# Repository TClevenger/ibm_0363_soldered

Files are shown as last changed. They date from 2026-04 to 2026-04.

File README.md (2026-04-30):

# IBM_0363_soldered

An alternative to the unobtainium/exhorbitantly expensive IBM 0363 (45H2433) port box for the Integrated Netfinity PC on the AS/400 Model 150 and probably others.  This breaks out the PS/2 keyboard and mouse ports from the MDR-40 mini-delta connector on the back of the Netfinity card set.  

This board is tested to fit CUI MD-60S Mini-DIN ports and uses any four-pair cable to connect to a 3M 10140-3000PE "solder cup" style connector.  Gerbers were made using JLCPCB template.

Current release is V1R1 (2026-04-30)
* Expanded pad size, added header vias, cleaned up silkscreen markings, narrowed strain relief holes
* Added LICENSE file

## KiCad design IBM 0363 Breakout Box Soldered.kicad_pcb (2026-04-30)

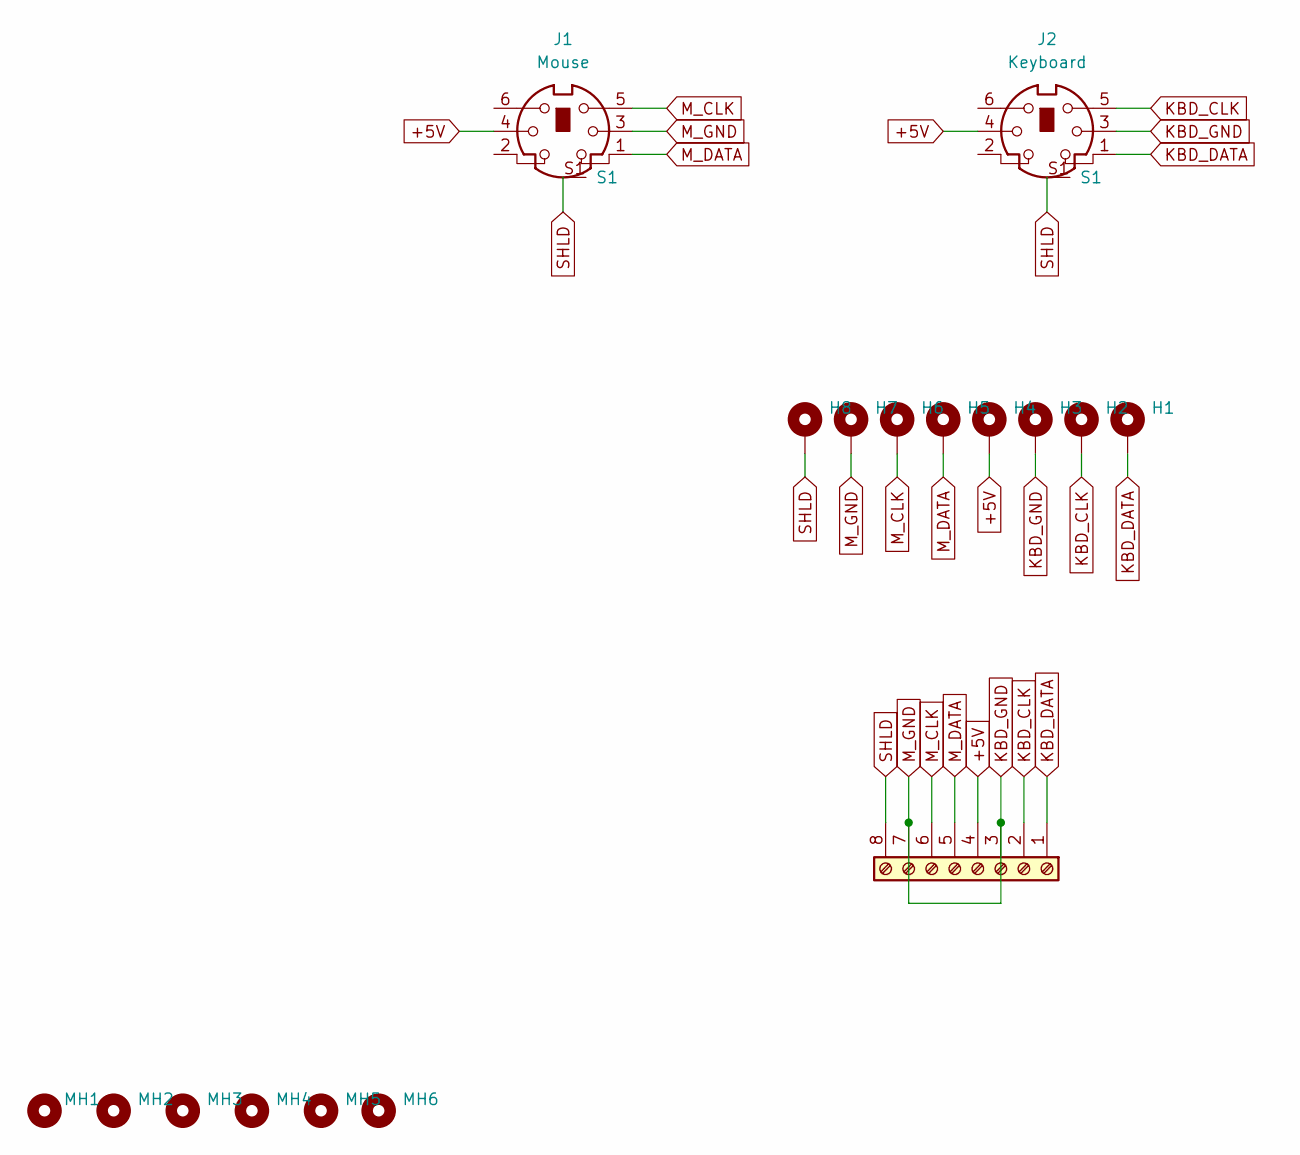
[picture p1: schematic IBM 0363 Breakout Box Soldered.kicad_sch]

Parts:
H1: MountingHole_Pad; SolderWirePad_1x01_SMD_2.5x5mm_P1
H2, H3, H4, H5, H6, H7, H8: MountingHole_Pad; SolderWirePad_1x01_SMD_1.5x3mm_P1
J1: Mouse; CUI_MD-60S
J2: Keyboard; CUI_MD-60S
J4: Screw_Terminal_01x08; PinHeader_1x08_P2.54mm_Horizontal
MH1, MH2, MH3, MH4, MH5, MH6: MountingHole; MountingHole_3.2mm_M3

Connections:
+5V: H4.1, J1.4, J2.4, J4.4
KBD_CLK: H2.1, J2.5, J4.2
KBD_DATA: H1.1, J2.1, J4.1
KBD_GND: H3.1, H7.1, J1.3, J2.3, J4.3, J4.7
M_CLK: H6.1, J1.5, J4.6
M_DATA: H5.1, J1.1, J4.5
SHLD: H8.1, J1.S1, J2.S1, J4.8

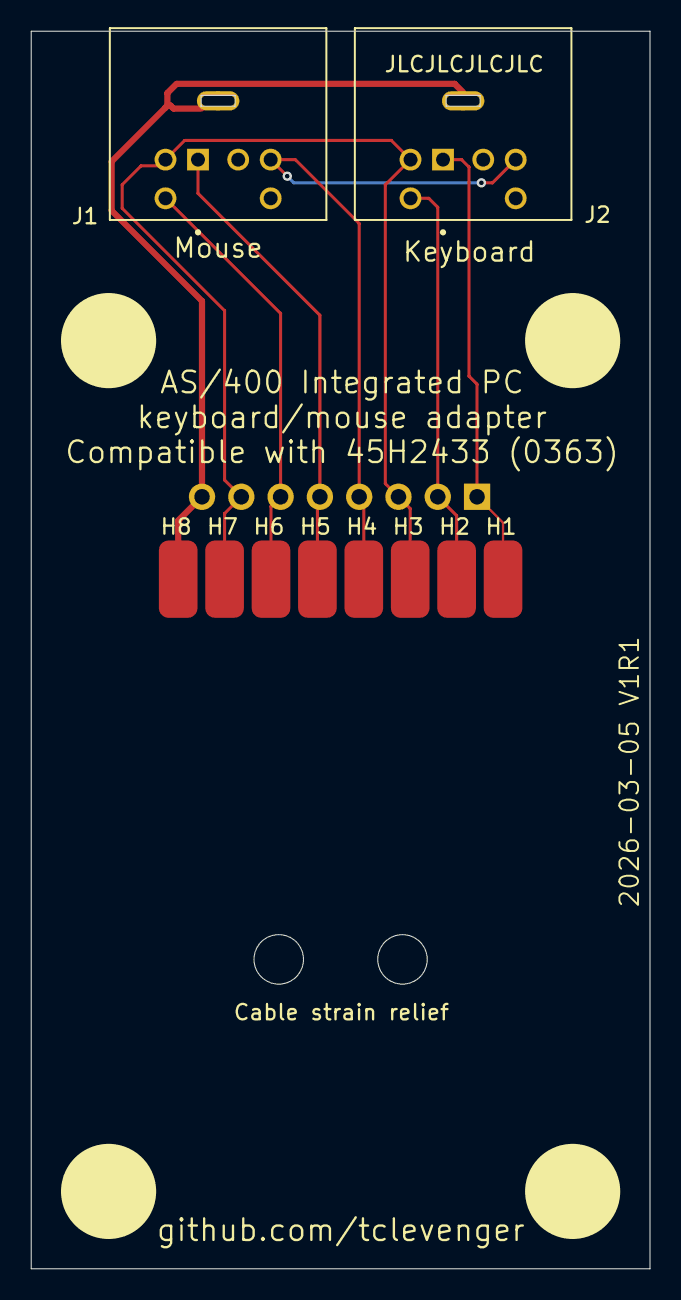
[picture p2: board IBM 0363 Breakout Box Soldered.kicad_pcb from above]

Board: 2 copper layers, 40.0 x 80.0 mm, 17 parts (1 on the bottom side), 7 nets.
